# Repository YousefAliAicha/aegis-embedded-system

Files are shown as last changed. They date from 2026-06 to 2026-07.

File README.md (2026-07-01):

# AEGIS — Networked Rotating Ultrasonic Radar System






AEGIS Dashboard

A real-time radar system built on the **Deneyap Kart 1A (ESP32-S3)**. AEGIS sweeps a servo-mounted HC-SR04 ultrasonic sensor across a 180° arc, streams live telemetry over WebSocket, and serves a full mission-control dashboard from the board itself — no external server, no app install, just a browser.

---

## Features

**Hardware**

- Continuous 0–180° servo sweep with configurable range, speed, and step size
- HC-SR04 ultrasonic ranging up to 300 cm
- 1602A LCD displaying live angle, distance, and detection state — flicker-free, no `clear()` in loop
- Graceful offline fallback: if Wi-Fi is unavailable the radar loop continues and the LCD remains live

**Web Dashboard** (served directly from the board at `http://<device-ip>`)

- Live radar scope with phosphor trail, sweep beam, and range rings
- Adjustable detection threshold ring rendered on-canvas
- **Manual Steer Mode** — click or drag on the radar canvas to aim the servo directly
- **Threat Perimeter** — draw a custom polygon on the radar; detections inside trigger a breach alarm
- Waterfall history strip showing distance over time
- Signal waveform panel with motion intensity meter
- Alert log with INNER / OUTER zone classification and unread badge counter
- **Audio Engine** — sonar ping tones scaled by target distance (Web Audio API)
- Animated globe widget with rotating world map and position marker
- System telemetry panel: CPU %, memory %, uptime, ESP32 chip temp
- Auto-reconnecting WebSocket — survives page reload and short network drops

**Firmware Controls** (all runtime-adjustable from the dashboard, no reflash needed)

| Command | Effect |
| --- | --- |
| `SET_SWEEP_MIN`  | Left boundary of sweep arc (0–180°) |
| `SET_SWEEP_MAX`  | Right boundary of sweep arc (0–180°)  |
| `SET_STEP_DEG` | Angular resolution per step (1–10°) |
| `SET_STEP_DELAY` | Milliseconds between steps (5–200 ms) |
| `SET_THRESHOLD`  | Detection distance in cm (1–300 cm) |
| `MANUAL_STEER` | Point servo to a specific angle |
| `AUTO_RESUME` | Return to automatic sweep |

▶ [Full demo on YouTube](https://youtu.be/lgbAfCLylXU)

---

## Hardware Requirements

| Component | Quantity | Notes |
| --- | --- | --- |
| Deneyap Kart 1A | 1 | ESP32-S3 based; other ESP32 boards require pin remapping |
| HC-SR04 Ultrasonic Sensor | 1 | 5 V supply required |
| SG90 Servo Motor | 1 | 5 V supply required; never power from board 3.3 V |
| 1602A LCD (HD44780-compatible) | 1 | 16-pin, 4-bit parallel mode |
| MB102 Breadboard Power Module  | 1 | Supplies 5 V to servo, sensor, and LCD |
| 9 V DC wall adapter | 1 | Centre-positive, ≥ 1 A; **do not use a 9 V PP3 battery** |
| 10 kΩ potentiometer | 1 | LCD contrast adjustment |
| 220 Ω resistor | 1 | LCD backlight current limiting |

---

## Wiring

Full pin-level connection map is in **[WIRING.md](WIRING.md)**.

Quick summary:

| Deneyap Pin | Connected to |
| --- | --- |
| D0 | SG90 PWM signal |
| D1 | HC-SR04 TRIG |
| D11 | HC-SR04 ECHO |
| D4 | LCD Enable |
| D5–D7 | LCD D4–D6 |
| D10 | LCD RS |
| D12 | LCD D7 |
| GND | MB102 GND rail (mandatory common ground) |

> **Critical:** The MB102 GND rail **must** be wired to the Deneyap Kart GND pin. Without a shared ground reference all signal levels are undefined.

---

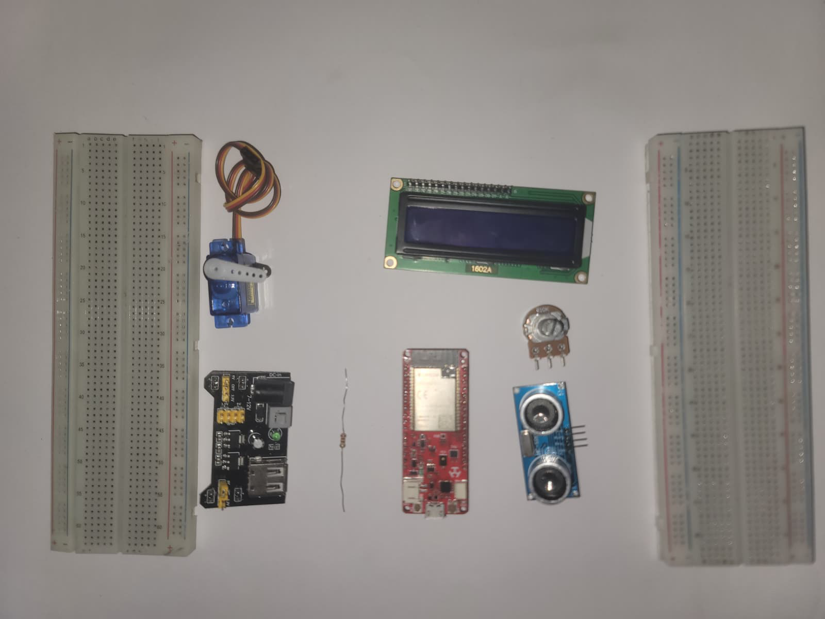
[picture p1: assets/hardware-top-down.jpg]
Hardware Setup


## Software Setup

### 1. Prerequisites

- [Arduino IDE 2.x](https://www.arduino.cc/en/software) (or Arduino CLI)
- Deneyap Kart board package installed in Arduino IDE
  - Add this URL under _File → Preferences → Additional boards manager URLs_:
    ```
    https://raw.githubusercontent.com/deneyapkart/deneyapkart-arduino-core/master/package_deneyapkart_index.json
    ```
  - Then install **Deneyap Kart** via _Tools → Board → Boards Manager_

### 2. Install Required Libraries

Open _Tools → Manage Libraries_ and install:

| Library | Author |
| --- | --- |
| WebSockets  | Markus Sattler |
| ESP32Servo  | Kevin Harrington |
| ArduinoJson | Benoit Blanchon  |

`LiquidCrystal` and `WiFi` are bundled with the Deneyap / ESP32 board package and require no separate install.

### 3. Configure Wi-Fi Credentials

Copy the example secrets file and fill in your network details:

```bash
cp firmware/aegis-deneyap/secrets.h.example firmware/aegis-deneyap/secrets.h
```

Edit `secrets.h`:

```cpp
#define WIFI_SSID     "your_network_name"
#define WIFI_PASSWORD "your_password"
```

> **`secrets.h` is listed in `.gitignore` and will never be committed.**

### 4. Flash the Board

1. Open `firmware/aegis-deneyap/aegis-deneyap.ino` in Arduino IDE
2. Select _Tools → Board → Deneyap Kart 1A_
3. Select the correct COM port under _Tools → Port_
4. Click **Upload**

On first boot the LCD will display `AEGIS v1.0` then `Connecting WiFi`. Once connected, the LCD shows the board's IP address for ~3 seconds before the radar loop begins.

### 5. Open the Dashboard

On any device connected to the same Wi-Fi network, open a browser and navigate to:

```
http://<ip shown on lcd or in serial monitor 115200>
```

The dashboard loads instantly — it is served directly from the board's flash memory. No internet connection is required after the fonts load on first visit (or if you remove the Google Fonts import from `dashboard.h` for fully offline use).

---

## Project Structure

```
aegis-embedded-system/
├── assets/                   # Images and media
├── firmware/
│   └── aegis-deneyap/
│       ├── aegis-deneyap.ino # Main firmware — radar loop, Wi-Fi, WebSocket server
│       ├── dashboard.h       # Self-contained HTML/CSS/JS dashboard, stored in ESP32 flash
│       ├── secrets.h         # Wi-Fi credentials — NOT committed (see .gitignore)
│       └── secrets.h.example # Template — copy this to secrets.h
├── hardware/
│   ├── aegis.kicad_sch       # KiCad schematic
│   ├── aegis.kicad_pcb       # KiCad PCB layout
│   ├── aegis.kicad_pro       # KiCad project file
│   └── HC-SR04/              # HC-SR04 sensor symbol/footprint reference
├── .gitignore
├── README.md
└── WIRING.md                 # Full pin-level wiring reference
```

---

## How It Works

AEGIS runs a **non-blocking sweep loop** — there is no `delay()` in the main loop. Each tick is gated by a millisecond timer, which keeps the WebSocket and HTTP stacks responsive between steps.

**Data flow:**

```
[Servo position] → [HC-SR04 pulse] → [distance measurement]
       ↓                                        ↓
  [LCD update]                     [WebSocket broadcast]
                                            ↓
                                   [Browser radar canvas]
```

**Inbound commands** from the browser arrive as JSON over WebSocket port 81 and are applied immediately to the live sweep parameters — no reflash, no restart.

**Offline mode:** if Wi-Fi association fails after 30 attempts (~12 seconds), AEGIS displays `OFFLINE MODE` on the LCD and continues the radar loop locally. The dashboard is unavailable in this state but all hardware functions normally.

---

## WebSocket Protocol

The board broadcasts one frame per sweep step on **port 81**.

**Outbound (board → browser):**

```json
{ "a": 90, "d": 34.2, "det": true }
```

- `a` — current servo angle (0–180°)
- `d` — measured distance in cm, or `-1` if out of range
- `det` — `true` if distance is within the detection threshold

**Inbound (browser → board):** see the [Firmware Controls](#firmware-controls) table above.

---

## License

MIT License — see [LICENSE](LICENSE) for full terms.
base) PS C:\Users\Yousef\Desktop\aegis-embedded-system> git add .
warning: in the working copy of 'firmware/aegis-deneyap/secrets.h', LF will be replaced by CRLF the next time Git touches it
warning: adding embedded git repository: hardware/.history
hint: You've added another git repository inside your current repository.
hint: Clones of the outer repository will not contain the contents of
hint: the embedded repository and will not know how to obtain it.
hint: If you meant to add a submodule, use:
hint:
hint: git submodule add <url> hardware/.history
hint:
hint: If you added this path by mistake, you can remove it from the
hint: index with:
hint:
hint: git rm --cached hardware/.history
hint:
hint: See "git help submodule" for more information.
hint: Disable this message with "git config set advice.addEmbeddedRepo false"
(base) PS C:\Users\Yousef\Desktop\aegis-embedded-system>

---

## Acknowledgements

- [WebSockets library](https://github.com/Links2004/arduinoWebSockets) — Markus Sattler
- [ESP32Servo](https://github.com/madhephaestus/ESP32Servo) — Kevin Harrington
- [ArduinoJson](https://arduinojson.org) — Benoit Blanchon
- Deneyap Kart hardware and board support — [Deneyap](https://deneyapkart.org)
- [HC-SR04 KiCad Model](https://www.snapeda.com/parts/HC-SR04/SparkFun/view-part/) — SparkFun

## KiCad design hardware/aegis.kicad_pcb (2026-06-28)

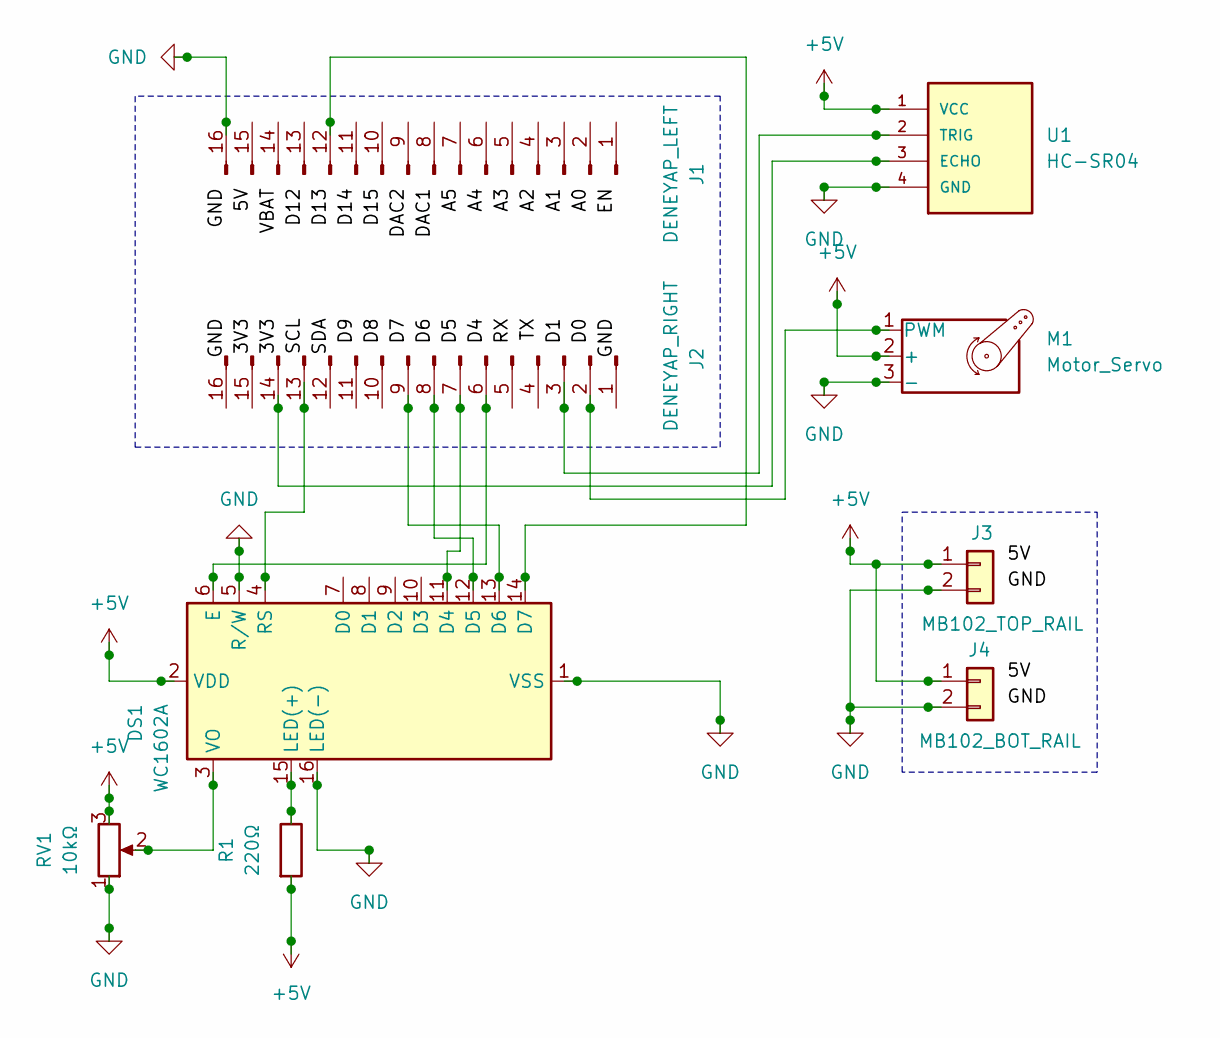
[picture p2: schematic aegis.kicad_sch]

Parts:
DS1: WC1602A
J1: DENEYAP_LEFT; PinHeader_1x16_P2.54mm_Vertical
J2: DENEYAP_RIGHT; PinHeader_1x16_P2.54mm_Vertical
J3: MB102_TOP_RAIL; PinHeader_1x02_P2.54mm_Vertical
J4: MB102_BOT_RAIL; PinHeader_1x02_P2.54mm_Vertical
M1: Motor_Servo; Harwin_M20-89003xx_1x03_P2.54mm_Horizontal
R1: 220Ω; R_0201_0603Metric
RV1: 10kΩ; Potentiometer_Bourns_3296W_Vertical
U1: HC-SR04; XCVR_HC-SR04

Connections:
+5V: DS1.2 (VDD), J3.1, J4.1, M1.2 (+), R1.2, RV1.3, U1.1 (VCC)
GND: DS1.1 (VSS), DS1.5 (R/W), DS1.16 (LED(-)), J1.16, J3.2, J4.2, M1.3 (-), RV1.1, U1.4 (GND)
unnamed: DS1.11 (D4), J2.7
unnamed: DS1.12 (D5), J2.8
unnamed: DS1.13 (D6), J2.9
unnamed: DS1.14 (D7), J1.12
unnamed: DS1.6 (E), J2.6
unnamed: DS1.15 (LED(+)), R1.1
unnamed: DS1.4 (RS), J2.13
unnamed: DS1.3 (VO), RV1.2
unnamed: J2.2, M1.1 (PWM)
unnamed: J2.3, U1.2 (TRIG)
unnamed: J2.14, U1.3 (ECHO)

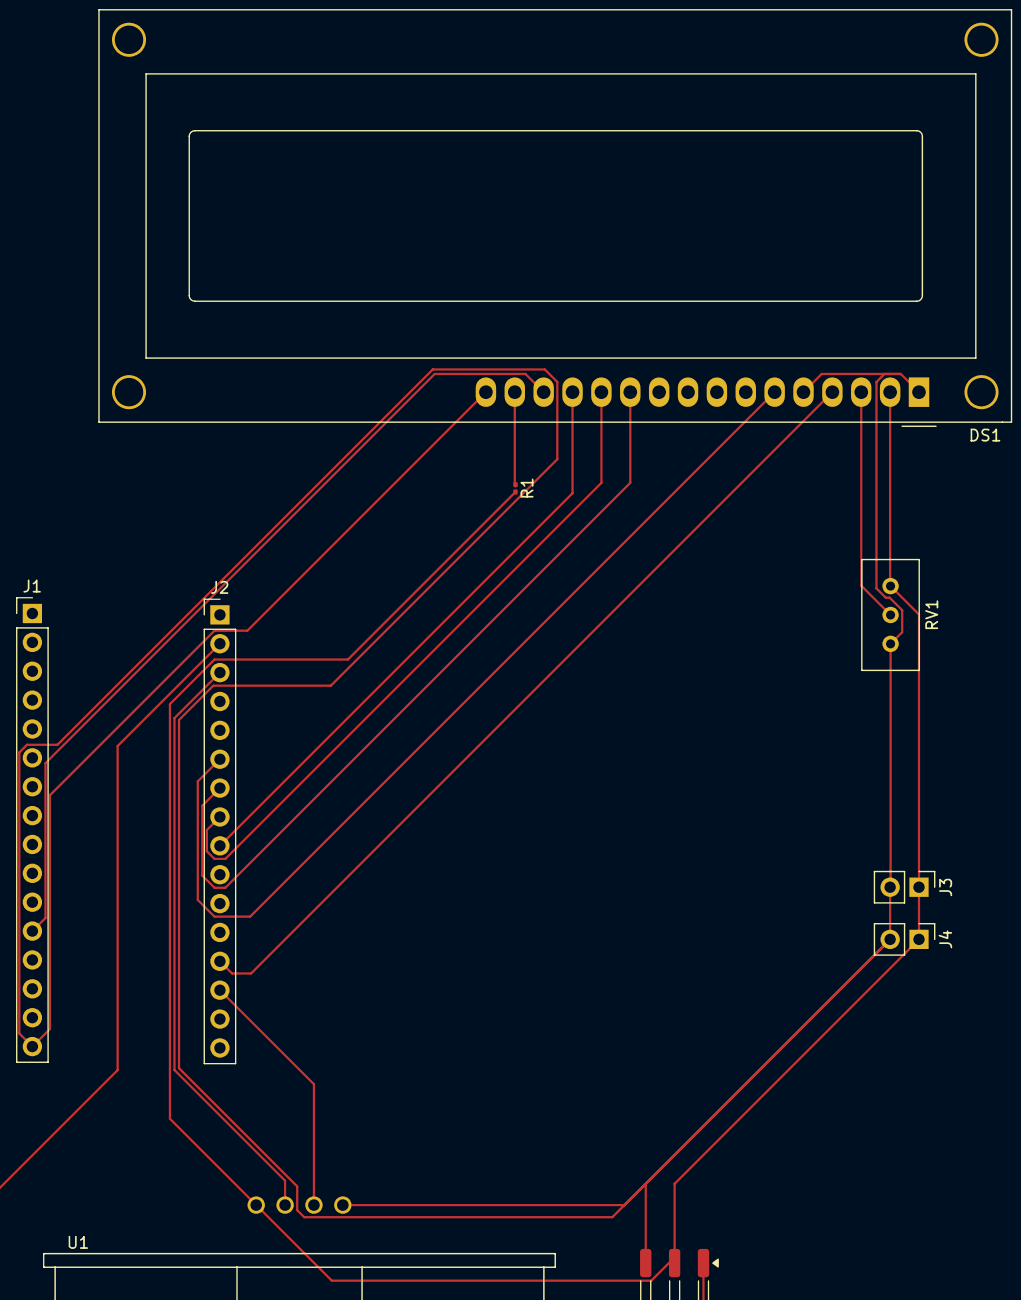
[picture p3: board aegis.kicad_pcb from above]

Board: 2 copper layers, 9 parts (0 on the bottom side), 13 nets.

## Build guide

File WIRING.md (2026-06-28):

# AEGIS — Wiring Reference

Complete pin-level connection map for the Deneyap Kart 1A build.

---

## 1602A LCD (16-pin, HD44780, 4-bit parallel mode)

| LCD Pin | Label | Connected to |
|---|---|---|
| 1  | VSS | GND (unified ground rail) |
| 2  | VDD | MB102 5 V output rail |
| 3  | VO  | 10 kΩ potentiometer wiper (divider between 5 V and GND) |
| 4  | RS  | D10 |
| 5  | R/W | GND (write-only mode — R/W is never needed in this project) |
| 6  | E | D4 |
| 7  | D0  | No connection |
| 8  | D1  | No connection |
| 9  | D2  | No connection |
| 10 | D3  | No connection |
| 11 | D4  | D5 |
| 12 | D5  | D6 |
| 13 | D6  | D7 |
| 14 | D7  | D12 |
| 15 | A (BLA) | 5 V via 220 Ω resistor (backlight anode) |
| 16 | K (BLK) | GND (backlight cathode) |

**Note on VO (contrast):** Wire a 10 kΩ potentiometer between the 5 V rail and GND. Connect the wiper to LCD pin 3. Adjust until characters are clearly visible. Do not use the direct-GND shortcut — it only works on some LCD batch variants. See [issue #4](./issue-04-lcd-batch-variance-friction-fit.md).

---

## HC-SR04 Ultrasonic Sensor

| HC-SR04 Pin | Connected to |
|---|---|
| VCC  | MB102 5 V output rail |
| TRIG | D1 |
| ECHO | D11 |
| GND  | GND (unified ground rail) |

**Note on ECHO voltage:** The HC-SR04 outputs a 5 V ECHO pulse. `D11` on the Deneyap Kart 1A handles this safely. Do not remap ECHO to an arbitrary GPIO without checking 5 V tolerance first.

---

## SG90 Servo Motor

| SG90 Wire | Colour (typical) | Connected to |
|---|---|---|
| GND | Brown / Black | GND (unified ground rail) |
| VCC | Red | MB102 5 V output rail |
| PWM | Orange / Yellow | D0 |

---

## MB102 Breadboard Power Module

| MB102 Terminal | Connected to |
|---|---|
| Input barrel jack | 9 V DC wall adapter, centre-positive, ≥ 1 A |
| 5 V output rail | Breadboard positive rail (feeds servo, HC-SR04, LCD) |
| GND output rail | Breadboard negative rail **and** Deneyap Kart GND pin |

**Critical:** The MB102 GND must be wired directly to the Deneyap Kart's GND pin. Without a common ground reference, all signal levels between the two supply domains are undefined.

**Do not use a 9 V PP3 battery** as the MB102 input. See [issue #5](./issue-05-9v-battery-unstable-mb102.md).

---

## Deneyap Kart 1A — Pin Summary

| Deneyap Pin | Function | Connected to |
|---|---|---|
| D0  | PWM output | SG90 signal wire |
| D1  | Digital output | HC-SR04 TRIG |
| D4  | Digital output | LCD E (Enable) |
| D5  | Digital output | LCD D4 |
| D6  | Digital output | LCD D5 |
| D7  | Digital output | LCD D6 |
| D10 | Digital output | LCD RS |
| D11 | Digital input  | HC-SR04 ECHO |
| D12 | Digital output | LCD D7 |
| GND | Ground reference | MB102 GND rail |

Pins D9, D14, and other flash-bus-adjacent lines are intentionally left unconnected. See [issue #1](./issue-01-flash-bus-pin-conflict.md).

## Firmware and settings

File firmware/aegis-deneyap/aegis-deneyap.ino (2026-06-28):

/*
 * ╔══════════════════════════════════════════════════════════════════╗
 * ║  AEGIS — Networked Rotating Ultrasonic Radar System  v1.0        ║
 * ║  Board   : Deneyap Kart 1A (ESP32-S3)                            ║
 * ║  LCD     : 1602A, HD44780-compatible, 4-bit parallel mode        ║
 * ║  Author  : [Yousef Ali Aicha]  |  Portfolio Project              ║
 * ╚══════════════════════════════════════════════════════════════════╝
 *
 *  Pin Assignments
 *  ───────────────────────────────────────────────────────────────────
 *  D0  ── SG90 servo PWM signal
 *  D1  ── HC-SR04 TRIG (10 µs output pulse)
 *  D11 ── HC-SR04 ECHO (input, isolated from flash bus)
 *
 *  D10 ── LCD RS  (Register Select)
 *  D4  ── LCD E   (Enable / clock)
 *  D5  ── LCD D4  (data bit 4)
 *  D6  ── LCD D5  (data bit 5)
 *  D7  ── LCD D6  (data bit 6)
 *  D12 ── LCD D7  (data bit 7, isolated from flash bus)
 *
 *  Power Notes
 *  ───────────────────────────────────────────────────────────────────
 *  SG90 VCC    → MB102 5 V rail (never power servo from board 3.3 V)
 *  HC-SR04 VCC → MB102 5 V rail
 *  LCD VDD     → MB102 5 V rail
 *  LCD VO      → GND  (10k Potentiometer Wiper)
 *  LCD RW      → GND  (write-only mode)
 *  MB102 GND   → Deneyap GND (mandatory common-ground reference)
 *
 *  Communication Protocol (WebSocket JSON)
 *  ───────────────────────────────────────────────────────────────────
 *  Outbound (ESP32 → browser), every sweep step:
 *    { "a": <angle 0-180>, "d": <dist cm | -1>, "det": <bool> }
 *
 *  Inbound commands (browser → ESP32):
 *    { "cmd": "SET_SWEEP_MIN",   "val": <0-180> }
 *    { "cmd": "SET_SWEEP_MAX",   "val": <0-180> }
 *    { "cmd": "SET_STEP_DELAY",  "val": <ms>    }
 *    { "cmd": "SET_THRESHOLD",   "val": <cm>    }
 *    { "cmd": "SET_STEP_DEG",    "val": <1-10>  }
 *    { "cmd": "MANUAL_STEER",    "val": <0-180> }
 *    { "cmd": "AUTO_RESUME"                     }
 */

#include <WiFi.h>
#include <WebServer.h>
#include <WebSocketsServer.h>   // Install: "WebSockets" by Markus Sattler
#include <ESP32Servo.h>         // Install: "ESP32Servo" by Kevin Harrington
#include <LiquidCrystal.h>      // Built-in Arduino library
#include <ArduinoJson.h>        // Install: "ArduinoJson" by Benoit Blanchon

#include "secrets.h"
#include "dashboard.h"          // self-contained HTML dashboard, served over HTTP

// ── Pin definitions ──────────────────────────────────────────────────
#define SERVO_PIN   D0
#define TRIG_PIN    D1
#define ECHO_PIN    D11

#define LCD_RS      D10
#define LCD_EN      D4
#define LCD_D4      D5
#define LCD_D5      D6
#define LCD_D6      D7
#define LCD_D7      D12

// ── Radar defaults (all runtime-adjustable via WebSocket commands) ───
#define DEFAULT_SWEEP_MIN_DEG      0
#define DEFAULT_SWEEP_MAX_DEG      180
#define DEFAULT_SWEEP_STEP_DEG     2
#define DEFAULT_STEP_DELAY_MS      25
#define DEFAULT_DETECT_THRESHOLD_CM 40
#define MAX_RANGE_CM               300
#define SONAR_TIMEOUT_US           30000   // ~514 cm, safely beyond MAX_RANGE_CM

// ── Objects ──────────────────────────────────────────────────────────
Servo            radarServo;
LiquidCrystal    lcd(LCD_RS, LCD_EN, LCD_D4, LCD_D5, LCD_D6, LCD_D7);
WebServer        httpServer(80);
WebSocketsServer wsServer(81);

// ── Runtime-tunable parameters ───────────────────────────────────────
int   sweepMinDeg      = DEFAULT_SWEEP_MIN_DEG;
int   sweepMaxDeg      = DEFAULT_SWEEP_MAX_DEG;
int   sweepStepDeg     = DEFAULT_SWEEP_STEP_DEG;
int   stepDelayMs      = DEFAULT_STEP_DELAY_MS;
int   detectThreshCm   = DEFAULT_DETECT_THRESHOLD_CM;

// ── Sweep state ──────────────────────────────────────────────────────
int           currentAngle   = DEFAULT_SWEEP_MIN_DEG;
int           sweepDir       = 1;          // +1 → towards max, -1 → towards min
float         currentDistCm  = -1.0f;
bool          detected       = false;
bool          manualMode     = false;      // pauses auto-sweep when true
unsigned long lastStepTime   = 0;

// ─────────────────────────────────────────────────────────────────────
//  SONAR — fires trigger pulse, measures echo, returns distance in cm.
//  Returns -1.0 on timeout (out of range) or readings beyond MAX_RANGE_CM.
// ─────────────────────────────────────────────────────────────────────
float measureDistanceCm() {
    digitalWrite(TRIG_PIN, LOW);
    delayMicroseconds(4);
    digitalWrite(TRIG_PIN, HIGH);
    delayMicroseconds(10);
    digitalWrite(TRIG_PIN, LOW);

    long duration = pulseIn(ECHO_PIN, HIGH, SONAR_TIMEOUT_US);
    if (duration == 0) return -1.0f;

    float cm = (duration * 0.0343f) / 2.0f;
    return (cm > MAX_RANGE_CM) ? -1.0f : cm;
}

// ─────────────────────────────────────────────────────────────────────
//  LCD — overwrites in place to prevent flicker (no lcd.clear() in loop)
// ─────────────────────────────────────────────────────────────────────
void updateLCD(int angle, float dist, bool det) {
    char row0[17];
    char row1[17];

    if (dist < 0.0f) {
        snprintf(row0, sizeof(row0), "A:%3d\xDF D: --- cm", angle);
    } else {
        snprintf(row0, sizeof(row0), "A:%3d\xDF D:%4dcm ", angle, (int)dist);
    }

    snprintf(row1, sizeof(row1), det ? "** DETECTED **  " : "  Scanning...   ");

    lcd.setCursor(0, 0); lcd.print(row0);
    lcd.setCursor(0, 1); lcd.print(row1);
}

// ─────────────────────────────────────────────────────────────────────
//  WebSocket — broadcast current telemetry frame to all connected clients
// ─────────────────────────────────────────────────────────────────────
void broadcastTelemetry() {
    // Short keys to minimise over-the-air JSON payload size
    StaticJsonDocument<128> doc;
    doc["a"]   = currentAngle;
    doc["d"]   = (currentDistCm < 0.0f) ? -1.0f : currentDistCm;
    doc["det"] = detected;

    char buf[128];
    serializeJson(doc, buf);
    wsServer.broadcastTXT(buf);
}

// ─────────────────────────────────────────────────────────────────────
//  WebSocket — parse and apply inbound command from browser
// ─────────────────────────────────────────────────────────────────────
void handleCommand(const String& raw) {
    StaticJsonDocument<128> doc;
    if (deserializeJson(doc, raw) != DeserializationError::Ok) return;

    const char* cmd = doc["cmd"];
    if (!cmd) return;

    if (strcmp(cmd, "SET_SWEEP_MIN") == 0) {
        sweepMinDeg = constrain((int)doc["val"], 0, sweepMaxDeg - 1);

    } else if (strcmp(cmd, "SET_SWEEP_MAX") == 0) {
        sweepMaxDeg = constrain((int)doc["val"], sweepMinDeg + 1, 180);

    } else if (strcmp(cmd, "SET_STEP_DELAY") == 0) {
        stepDelayMs = constrain((int)doc["val"], 5, 200);

    } else if (strcmp(cmd, "SET_THRESHOLD") == 0) {
        detectThreshCm = constrain((int)doc["val"], 1, MAX_RANGE_CM);

    } else if (strcmp(cmd, "SET_STEP_DEG") == 0) {
        sweepStepDeg = constrain((int)doc["val"], 1, 10);

    } else if (strcmp(cmd, "MANUAL_STEER") == 0) {
        manualMode   = true;
        currentAngle = constrain((int)doc["val"], 0, 180);
        radarServo.write(currentAngle);

    } else if (strcmp(cmd, "AUTO_RESUME") == 0) {
        manualMode = false;
    }
}

// ─────────────────────────────────────────────────────────────────────
//  WebSocket event handler
// ─────────────────────────────────────────────────────────────────────
void onWebSocketEvent(uint8_t clientId,
                      WStype_t type,
                      uint8_t* payload,
                      size_t   length)
{
    switch (type) {
        case WStype_CONNECTED:
            Serial.printf("[WS] Client #%u connected\n", clientId);
            break;

        case WStype_DISCONNECTED:
            Serial.printf("[WS] Client #%u disconnected\n", clientId);
            break;

        case WStype_TEXT:
            handleCommand(String((char*)payload));
            break;

        default:
            break;
    }
}

// ─────────────────────────────────────────────────────────────────────
//  HTTP — serve the self-contained dashboard (stored in dashboard.h)
// ─────────────────────────────────────────────────────────────────────
void handleRoot() {
    httpServer.send_P(200, "text/html", DASHBOARD_HTML);
}

// ─────────────────────────────────────────────────────────────────────
//  SETUP
// ─────────────────────────────────────────────────────────────────────
void setup() {
    Serial.begin(115200);

    // LCD
    lcd.begin(16, 2);
    lcd.clear();
    lcd.setCursor(0, 0); lcd.print("AEGIS  v1.0     ");
    lcd.setCursor(0, 1); lcd.print("Initialising... ");

    // GPIO
    pinMode(TRIG_PIN, OUTPUT);
    pinMode(ECHO_PIN, INPUT);
    digitalWrite(TRIG_PIN, LOW);

    // Servo — park at minimum angle
    radarServo.attach(SERVO_PIN, 500, 2400);
    radarServo.write(sweepMinDeg);
    delay(500);

    // Wi-Fi
    lcd.setCursor(0, 1); lcd.print("Connecting WiFi ");
    WiFi.begin(WIFI_SSID, WIFI_PASSWORD);

    int attempts = 0;
    while (WiFi.status() != WL_CONNECTED && attempts < 30) {
        delay(400);
        Serial.print('.');
        attempts++;
    }

    lcd.clear();

    if (WiFi.status() == WL_CONNECTED) {
        // HTTP server — serves dashboard page
        httpServer.on("/", handleRoot);
        httpServer.begin();

        // WebSocket server on port 81
        wsServer.begin();
        wsServer.onEvent(onWebSocketEvent);

        lcd.setCursor(0, 0); lcd.print("ONLINE          ");
        lcd.setCursor(0, 1); lcd.print(WiFi.localIP());

        Serial.printf("\n[AEGIS] Dashboard → http://%s\n",
                      WiFi.localIP().toString().c_str());
        Serial.printf("[AEGIS] WebSocket → ws://%s:81\n",
                      WiFi.localIP().toString().c_str());
        delay(3000);
    } else {
        lcd.setCursor(0, 0); lcd.print("WIFI TIMEOUT    ");
        lcd.setCursor(0, 1); lcd.print("OFFLINE MODE    ");
        Serial.println("\n[AEGIS] Wi-Fi failed. Running offline radar loop.");
        delay(2000);
    }

    lcd.clear();
    lastStepTime = millis();
}

// ─────────────────────────────────────────────────────────────────────
//  MAIN LOOP
// ─────────────────────────────────────────────────────────────────────
void loop() {
    // Service WebSocket and HTTP stacks
    if (WiFi.status() == WL_CONNECTED) {
        wsServer.loop();
        httpServer.handleClient();
    }

    unsigned long now = millis();

    // Non-blocking sweep tick
    if (!manualMode && (now - lastStepTime >= (unsigned long)stepDelayMs)) {
        lastStepTime = now;

        radarServo.write(currentAngle);

        float dist = measureDistanceCm();
        bool  det  = (dist > 0.0f && dist < detectThreshCm);

        currentDistCm = dist;
        detected      = det;

        updateLCD(currentAngle, dist, det);
        broadcastTelemetry();

        Serial.printf("[AEGIS] Pos: %3d° | Dist: ", currentAngle);
        if (dist < 0.0f) Serial.print("  OOR     ");
        else             Serial.printf("%5.1f cm  ", dist);
        Serial.println(det ? "[INTERCEPTED]" : "[CLEAR]");

        // Advance angle and reverse at boundaries
        currentAngle = constrain(
            currentAngle + (sweepDir * sweepStepDeg),
            sweepMinDeg,
            sweepMaxDeg
        );

        if (currentAngle >= sweepMaxDeg) sweepDir = -1;
        else if (currentAngle <= sweepMinDeg) sweepDir = 1;
    }
}
